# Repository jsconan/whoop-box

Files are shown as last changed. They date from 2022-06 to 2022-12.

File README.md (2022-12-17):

# whoop-box

A printable box system to store tiny-whoops.

<!-- vscode-markdown-toc -->

-   [At a glance](#Ataglance)
-   [Whoop boxes](#Whoopboxes)
-   [Batteries' box](#Batteriesbox)
-   [Angled boxes](#Angledboxes)
-   [Install and requirements](#Installandrequirements)
    -   [OpenSCAD](#OpenSCAD)
    -   [Source code](#Sourcecode)
        -   [Download the zip file](#Downloadthezipfile)
        -   [Get the code from the repository](#Getthecodefromtherepository)
    -   [Configuration](#Configuration)
-   [Render the parts](#Rendertheparts)
-   [Post-scripts](#Post-scripts)

<!-- vscode-markdown-toc-config
	numbering=false
	autoSave=true
	/vscode-markdown-toc-config -->
<!-- /vscode-markdown-toc -->

## At a glance

The project contains designs for a box system for storing tiny-whoop quadcopters. The parts are designed using a scripting language, processed by [OpenSCAD](https://openscad.org/about.html). There is no ready to use 3D model files in the source code. If you are interested in such files, please look at the [released versions](https://github.com/jsconan/whoop-box/releases) which contains 3D model files built with default parameters. However, if you want to customize these parts, tailoring them with your measures, you should rather download the source code and then tweak the configuration files before generating your own 3D model files.

At that time, the project proposes 3 sets of boxes. The dimensions and the number of cells can be set from the [configuration](./config/config-dist.scad).

The size is defined by (in millimeters):

-   The distance between motors, on the [diagonal](./config/config-dist.scad#L61).
-   The diameter of [ducts](./config/config-dist.scad#L62).
-   The height of [ducts](./config/config-dist.scad#L63).
-   The overall height of the [whoop](./config/config-dist.scad#L64).
-   The [padding](./config/config-dist.scad#L65) added between the box wall and the whoop.

A box is also available for enclosing a set of batteries. Its size can be configured too (millimeters):

-   The [width](./config/config-dist.scad#L74) of the battery.
-   The [thickness](./config/config-dist.scad#L75) of the battery.
-   The [length](./config/config-dist.scad#L76) of the battery.

The number of cells for each box is also configurable:

-   The [number of whoops per lines](./config/config-dist.scad#L69) (horizontal).
-   The [number of whoops per columns](./config/config-dist.scad#L70) (vertical).
-   The [number of whoops per lines and columns](./config/config-dist.scad#L71) (depth).
-   The [number of batteries per boxes](./config/config-dist.scad#L79).

Several presets are available out of the box in the file [config/presets.scad](./config/presets-dist.scad). The currently selected preset is configured through the variable `preset` in the file [config/config.scad](./config/config-dist.scad#L58).

When using the [render](./render.sh) script, all presets can be rendered at once using the option `-a`. See the section **[Render the parts](#Rendertheparts)**. Otherwise, only one single preset is rendered at a time.

## Whoop boxes

A second iteration on the project added simple boxes with padding inside to better wrap the tiny-whoop. Instead of multiple shells made of several materials, it only relies on a single box and its container.

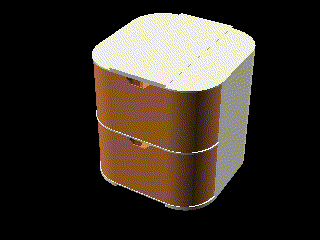
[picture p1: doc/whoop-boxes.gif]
simple box set


This version proposes several variants of the box:

-   A padded box to contain a tiny-whoop

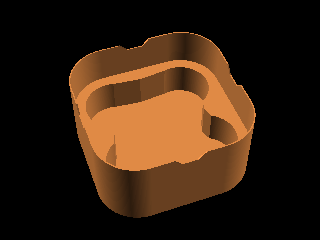
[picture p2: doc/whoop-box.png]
padded box


-   A box for spare parts

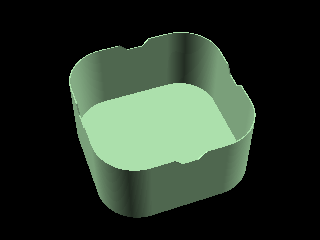
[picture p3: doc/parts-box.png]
spare part box


-   A box for propellers

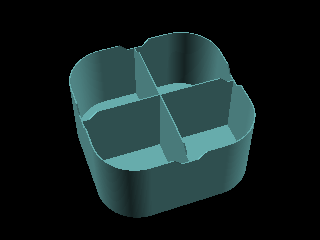
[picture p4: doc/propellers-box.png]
propellers box


-   A container for one or more boxes with respect to the configuration

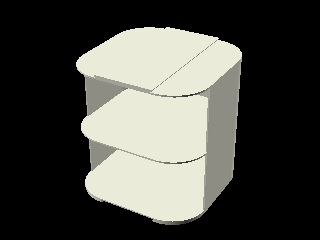
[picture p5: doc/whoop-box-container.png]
container


## Batteries' box

Aside the boxes for containing tiny-whoops, the project also proposes a parametric box for containing the batteries. The size of the batteries and the number per boxes can be configured.

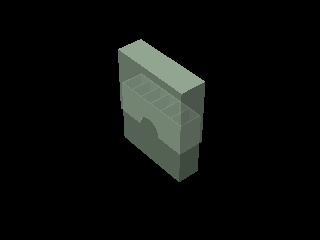
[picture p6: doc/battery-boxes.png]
batteries box


This box is made of two parts:

-   A batteries' container, with separators:

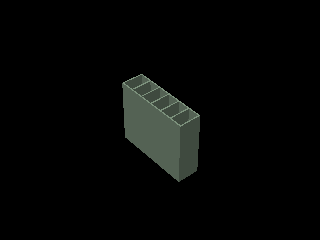
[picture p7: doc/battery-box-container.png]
batteries container


-   A box cover:

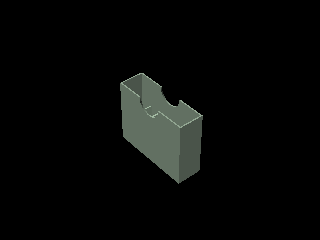
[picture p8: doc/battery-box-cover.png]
box cover


## Angled boxes

Initially, the project was based on a set of wrapped boxes, to be printed in various materials (TPU, PLA, PET). The set was made modular, in order to either have a simple box to protect a tiny-whoop or to properly store several of them in a cupboard.

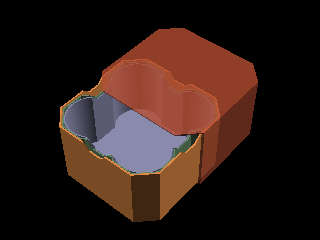
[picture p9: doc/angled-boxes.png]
angled box set


The proposed boxes are:

-   A rounded box to contain a tiny-whoop

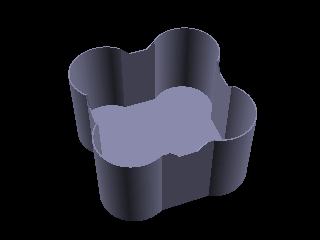
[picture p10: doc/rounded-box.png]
rounded box


-   An angled box to contain the rounded box

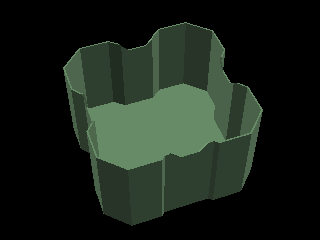
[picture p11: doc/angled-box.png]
angled box


-   A drawer to contain one or more angled boxes with respect to the configuration

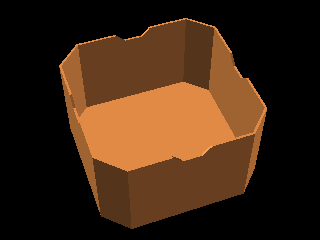
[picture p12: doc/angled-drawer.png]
angled drawer


-   A cupboard to contain drawers with one or more angled boxes with respect to the configuration

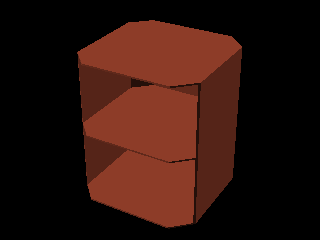
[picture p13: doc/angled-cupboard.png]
angled cupboard


## Install and requirements

To properly use the project you first need to do some installations steps.

### OpenSCAD

First of all you need [OpenSCAD](https://openscad.org/) to be installed. To do so, please go to the [OpenSCAD download page](https://openscad.org/downloads.html), an get the version suitable for your operating system.

### Source code

The source code is hosted on a [Git](https://git-scm.com/) repository. To get it you can either download a [zip file](https://github.com/jsconan/whoop-box/archive/refs/heads/main.zip), or clone the repository locally.

#### Download the zip file

The source code can be downloaded from the [GitHub repository](https://github.com/jsconan/whoop-box).

You can download it as zip file from this [link](https://github.com/jsconan/whoop-box/archive/refs/heads/main.zip).

As the project is using a shared library, that is not supplied with the package, you will need to also download it.

Download the zip file from this [link](https://github.com/jsconan/camelSCAD/archive/refs/heads/main.zip).

Then extract its content inside the folder `lib/camelSCAD`. Please make sure the folder directly contains the library and not an intermediate folder like `lib/camelSCAD/camelSCAD-main`. If this is the case, please move the content one folder up and delete the extra folder.

Note: the easiest way is to call the `init.sh` script, that will take care of this for you.

#### Get the code from the repository

A git tool is needed if you intend to get the source code from the git repository. You can download one either from the [main git website](https://git-scm.com/downloads), or from [GitHub](https://docs.github.com/en/github-cli).

Once you have your git tool installed, open a console window, select a project folder (create it if needed), then run the following commands:

```
git clone https://github.com/jsconan/whoop-box.git
cd whoop-box
git submodule init
git submodule update
```

The source code should have been downloaded, as well as the libraries.

Note: you can also use a graphical interface tool. In this case, please make it can also install the submodules.

Note 2: the easiest way is to call the `init.sh` script, that will take care of this for you.

### Configuration

The configuration may be changed locally. To not collide with changes in the main implementation, the configuration files are not versioned. Instead, you will find `-dist` files that contain a copy of the typical configuration.

From a fresh copy of the project, you will need first to create these configuration files. The easiest way is to call the `init.sh` script, that will take care of this for you. The configuration files will also be checked and created if needed each time the `render.sh` script is called.

This initial creation of the configuration files could also be done manually. Here is how:

1. Go to the `config` folder
2. Copy any of the files having a `-dist` suffix in their name to a file without this suffix.

    _Example:_ copy `config-dist.scad` to `config.scad`

## Render the parts

The parts are all located into the `parts` folder. They can all be opened separately in [OpenSCAD](https://openscad.org/) and rendered.

However, it is possible to render all parts in batch. The script `render.sh` takes care of this.

This is a command-line tool, which accept several parameters. By default, it will render the preset selected in the config.

It is possible to select another preset, as well as set a different number of cells for the containers.

The parameter `-h` make it show the help.

Running the command `render.sh -h` will show this message:

```
Renders OpenSCAD files
  Usage:
	./render.sh [command] [-h|--help] [-o|--option value] files

  a,   all            Render all elements (default)
  n,   angled         Render the sets of angled boxes
  w,   whoop          Render the sets of whoop boxes
  b,   battery        Render the sets of battery boxes
  -h,  --help         Show this help
  -p   --preset       Set the preset to apply
  -a,  --all          Render all presets
  -x,  --line         Set the number of boxes per lines in the container (X-axis)
  -y   --column       Set the number of boxes per columns in the container (Y-axis)
  -z   --depth        Set The number of boxes per lines and columns in the container (Z-axis)
  -b   --batteries    Set The number of batteries per boxes
  -f   --format       Set the output format
  -p   --parallel     Set the number of parallel processes
  -s   --slice        Slice the rendered files using the default configuration
  -c   --clean        Clean up the output folder before rendering
```

All presets can be rendered at once by calling the command `render.sh -a`.

The STL files are rendered to the `dist/stl` folder.

If the slicer [PrusaSlicer](https://github.com/prusa3d/PrusaSlicer) is installed, running the command `render.sh -s` will produce the [G-code](https://en.wikipedia.org/wiki/G-code) from the rendered STL files and using the setting from the file `config/config.ini`. Out of the box, it is produce instruction for PETG and a 0.2mm layer height.

## Post-scripts

When using the built-in script to render/slice the models in batch, you can also add custom post-processing scripts. There is one for `render.sh` and one for `slice.sh`. They are respectively named `post-render.sh` and `post-slice.sh`.

As these script can be defined locally, they are not part of the versioned content. Instead, you can find sample files at `post-render-dist.sh` and `post-slice-dist.sh`. To use them, you need to:

-   copy the dist file to a local file, for example: `cp post-render-dist.sh post-render.sh`.
-   you need to make sure the file is executable: `chmod +x post-render.sh`.
-   finally, add you own commands to the copy.

As an example:

-   The script used to zip the rendered files:

```sh
# Bootstrap the script
scriptpath=$(dirname $0)
source "${scriptpath}/lib/camelSCAD/scripts/utils.sh"

# Script config
project=$(pwd)
stlpath="${project}/dist/stl/"
zippath="stl.zip"
logpath="${project}/dist/zip.log"

# Post process the rendered files
printmessage "${C_MSG}==========================================="
printmessage "${C_MSG}Post-render script: zip files"
dummy=$(
    cd "${stlpath}"
    rm *.zip > /dev/null
    zip -r "${zippath}" *
)
printmessage "${C_MSG}==========================================="
```

-   The script used to copy the sliced files to a SD-card:

```sh
# Bootstrap the script
scriptpath=$(dirname $0)
source "${scriptpath}/lib/camelSCAD/scripts/utils.sh"

# Script config
project=$(pwd)
gcodepath="${project}/dist/gcode/"
sdcardpath="/PATH/TO/SD/CARD"
logpath="${project}/dist/gcode-sync.log"

# Post process the sliced files
printmessage "${C_MSG}==========================================="
printmessage "${C_MSG}Post-slice script: copy Gcode to the SDcard"
date > ${logpath}
createpath "${sdcardpath}"
rsync -ahvt --no-links --delete --partial --force --modify-window=1 --exclude=.DS_Store --log-file=${logpath} "${gcodepath}" "${sdcardpath}"
printmessage "${C_MSG}==========================================="
```

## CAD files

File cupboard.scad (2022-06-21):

/**
 * @license
 * GPLv3 License
 *
 * Copyright (c) 2019-2022 Jean-Sebastien CONAN
 *
 * This file is part of jsconan/whoop-box.
 *
 * jsconan/whoop-box is free software: you can redistribute it and/or modify
 * it under the terms of the GNU General Public License as published by
 * the Free Software Foundation, either version 3 of the License, or
 * (at your option) any later version.
 *
 * jsconan/whoop-box is distributed in the hope that it will be useful,
 * but WITHOUT ANY WARRANTY; without even the implied warranty of
 * MERCHANTABILITY or FITNESS FOR A PARTICULAR PURPOSE.  See the
 * GNU General Public License for more details.
 *
 * You should have received a copy of the GNU General Public License
 * along with jsconan/whoop-box. If not, see <http://www.gnu.org/licenses/>.
 */

/**
 * A box to store tiny-whoops.
 *
 * Cupboard that will contain several tiny-whoops and their surrounding
 * protection boxes. This should be printed in rigid a material, like PLA
 * or PETG.
 *
 * @author jsconan
 */

// Import the project's setup.
include <config/setup.scad>

// Sets the minimum facet angle and size using the defined render mode.
// Displays a build box visualization to preview the printer area.
applyMode(mode=renderMode) {
    // Uncomment the next line to cut a sample from the object
    //sample(size=[DEFAULT_BUILD_PLATE_SIZE, DEFAULT_BUILD_PLATE_SIZE, 5], offset=[0, 0, 20])
    whoopCupboard(
        whoopType = whoopType,
        whoopCount = whoopCountDrawer,
        drawerWallThickness = getBoxWallThickness(DRAWER),
        drawerHeight = getBoxHeight(CUPBOARD, whoopType),
        drawerCount = drawerCountCupboard,
        drawerDistance = getBoxWallDistance(CUPBOARD),
        ductDistance = getBoxWhoopDistance(DRAWER),
        wallThickness = getBoxWallThickness(CUPBOARD)
    );
}

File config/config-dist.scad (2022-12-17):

/**
 * @license
 * GPLv3 License
 *
 * Copyright (c) 2019-2022 Jean-Sebastien CONAN
 *
 * This file is part of jsconan/whoop-box.
 *
 * jsconan/whoop-box is free software: you can redistribute it and/or modify
 * it under the terms of the GNU General Public License as published by
 * the Free Software Foundation, either version 3 of the License, or
 * (at your option) any later version.
 *
 * jsconan/whoop-box is distributed in the hope that it will be useful,
 * but WITHOUT ANY WARRANTY; without even the implied warranty of
 * MERCHANTABILITY or FITNESS FOR A PARTICULAR PURPOSE.  See the
 * GNU General Public License for more details.
 *
 * You should have received a copy of the GNU General Public License
 * along with jsconan/whoop-box. If not, see <http://www.gnu.org/licenses/>.
 */

/**
 * A box to store tiny-whoops.
 *
 * Global configuration.
 *
 * @author jsconan
 */

// We will render the object using the specifications of this mode.
renderMode = MODE_PROD;

// Defines the characteristics of the printer
layerHeight = 0.2;          // The height of the printed layers.
nozzleWidth = 0.4;          // The size of the printer's nozzle.
printTolerance = 0.1;       // The print tolerance when pieces need to be assembled.
printInterval = 5;          // The interval between 2 pieces when presented together.
printerLength = 250;        // The length of the printer's build plate.
printerWidth = 210;         // The width of the printer's build plate.

// Options for the metadata. The render script uses them to extract infos.
showConfig = 0;             // Show the config when rendering a whoop box.
showBatteryConfig = 0;      // Show the config when rendering a battery box.
showPresets = 0;            // Show the list of available presets.
showBatteryPresets = 0;     // Show the list of available battery presets.
showSteps = 0;              // Show the expected number of steps for the whole animation

// Specifications for the boxes
wallThickness = 0.8;        // The thickness of the box walls.
containerThickness = 1.2;   // The thickness of the container walls.
groundThickness = 0.8;      // The thickness of the box ground.
linkThickness = 2;          // The thickness of the link elements.
boxIndentation = [30, 10];  // Defines the size of a handle indentation, it will be cut from each box side. The first value represents the top width, the second represents the bottom width and the depth.
outerDistance = 0.5;        // The distance between a box and its container. This is additional size added to the container inner room to fit the box.

// Select the config preset
preset = "DEFAULT";

// Defines the size of a tiny-whoop
motorDistance = getPreset(preset, IDX_MOTOR_DISTANCE);   // The distance between motors on the diagonal.
ductDiameter = getPreset(preset, IDX_DUCT_DIAMETER);     // The outer diameter of a motor duct.
ductHeight = getPreset(preset, IDX_DUCT_HEIGHT);         // The outer height of a motor duct, including the screw heads.
whoopHeight = getPreset(preset, IDX_WHOOP_HEIGHT);       // The outer height of the tiny-whoop, from the bottom of the frame to the top of the canopy, including everything beyond.
boxPadding = getPreset(preset, IDX_BOX_PADDING);         // The width of padding between the box sides and the tiny-whoop.
boxSeparators = getPreset(preset, IDX_BOX_SEPARATOR);    // Tells whether the box contains separators or not.

// Sets the count of tiny-whoops in each kind of box
whoopBoxX = getPreset(preset, IDX_BOX_X, 1);              // The number of boxes per lines in the container (horizontal axis).
whoopBoxY = getPreset(preset, IDX_BOX_Y, 1);              // The number of boxes per columns in the container (vertical axis).
whoopBoxZ = getPreset(preset, IDX_BOX_Z, 1);              // The number of boxes per lines and columns in the container (depth axis).

// Defines the size of a tiny-whoop's battery
batteryWidth = getBatteryPreset(preset, IDX_BATTERY_WIDTH);    // The battery width.
batteryHeight = getBatteryPreset(preset, IDX_BATTERY_HEIGHT);  // The battery height (thickness).
batteryLength = getBatteryPreset(preset, IDX_BATTERY_LENGTH);  // The battery height.

// Sets the count of batteries in each box
batteryNumber = getBatteryPreset(preset, IDX_BATTERY_NUMBER);  // The number of batteries.

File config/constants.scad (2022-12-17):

/**
 * @license
 * GPLv3 License
 *
 * Copyright (c) 2022 Jean-Sebastien CONAN
 *
 * This file is part of jsconan/whoop-box.
 *
 * jsconan/whoop-box is free software: you can redistribute it and/or modify
 * it under the terms of the GNU General Public License as published by
 * the Free Software Foundation, either version 3 of the License, or
 * (at your option) any later version.
 *
 * jsconan/whoop-box is distributed in the hope that it will be useful,
 * but WITHOUT ANY WARRANTY; without even the implied warranty of
 * MERCHANTABILITY or FITNESS FOR A PARTICULAR PURPOSE.  See the
 * GNU General Public License for more details.
 *
 * You should have received a copy of the GNU General Public License
 * along with jsconan/whoop-box. If not, see <http://www.gnu.org/licenses/>.
 */

/**
 * A box to store tiny-whoops.
 *
 * Global constants.
 *
 * @author jsconan
 */

// Defines the indexes in the presets
IDX_NAME           =  0; // The index for the preset name.
IDX_MOTOR_DISTANCE =  1; // The index for the distance between motors on the diagonal.
IDX_DUCT_DIAMETER  =  2; // The index for the outer diameter of a motor duct.
IDX_DUCT_HEIGHT    =  3; // The index for the outer height of a motor duct, including everything beyond like the screw heads.
IDX_WHOOP_HEIGHT   =  4; // The index for the outer height of the tiny-whoop, from the bottom of the frame to the top of the canopy, including everything beyond.
IDX_BOX_PADDING    =  5; // The index for the width of padding between the box sides and the tiny-whoop.
IDX_BOX_SEPARATOR  =  6; // The index for the flag allowing to add separators.
IDX_BOX_X          =  7; // The index for the number of boxes per lines in the container (horizontal axis).
IDX_BOX_Y          =  8; // The index for the number of boxes per columns in the container (vertical axis).
IDX_BOX_Z          =  9; // The index for the number of boxes per lines and columns in the container (depth axis).
IDX_BATTERY_WIDTH  =  1; // The index for the battery width.
IDX_BATTERY_HEIGHT =  2; // The index for the battery height.
IDX_BATTERY_LENGTH =  3; // The index for the battery length.
IDX_BATTERY_NUMBER =  4; // The index for the number of batteries per box.

// Colors applied to the elements when previewed.
// This will be used for the animations and other pictures, but this won't have effect on the ready to print elements.
colorWhoopBox = "#d84";                         // Color of a simple whoop box.
colorPropellersBox = "#6aa";                    // Color of a box for propellers.
colorPartsBox = "#ada";                         // Color of a box for spare parts.
colorWhoopBoxContainer = "#eed";                // Color of a whoop box container.
colorAngledBox = "#686";                        // Color of an angled box.
colorRoundedBox = "#88a";                       // Color of a rounded box.
colorAngledDrawer = "#d84";                     // Color of a drawer for angled boxes.
colorAngledCupboard = [.7, .3, .2, .8];         // Color of a cupboard for angled boxes.
colorBatteryBoxContainer = [.6, .7, .6, .8];    // Color of a battery container.
colorBatteryBoxCover = [.7, .8, .7, .8];        // Color of a battery box cover.

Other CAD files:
pictures/angled-cupboard.scad
angled-box.scad
config/helpers.scad
config/presets-dist.scad
config/setup.scad
config/version.scad
container.scad
drawer.scad
parts/angled/angled-box.scad
parts/angled/angled-container.scad
parts/angled/angled-cupboard.scad
parts/angled/angled-drawer.scad
parts/angled/rounded-box.scad
parts/battery/battery-box-container.scad
parts/battery/battery-box-cover.scad
parts/battery/battery-box.scad
parts/whoop/whoop-box-container.scad
parts/whoop/whoop-box.scad
pictures/angled-box.scad
pictures/angled-boxes.scad
pictures/angled-drawer.scad
pictures/battery-box-container.scad
pictures/battery-box-cover.scad
pictures/battery-boxes.scad
pictures/parts-box.scad
pictures/propellers-box.scad
pictures/rounded-box.scad
pictures/whoop-box-container.scad
pictures/whoop-box.scad
pictures/whoop-boxes.scad
rounded-box.scad
shapes/angled-box.scad
shapes/angled-container.scad
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

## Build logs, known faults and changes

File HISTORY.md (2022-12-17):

# whoop-box history

## [Version 1.1.0](https://github.com/jsconan/whoop-box/releases/tag/1.1.0)

Features:

-   Add a box containing a set of batteries.
    batteries box

-   Add actual example for the post render scripts.
-   Add a preset for Meteor65 Pro 2022 edition

Fixes:

-   Add a forgotten picture in the readme.
-   Fix a misaligned comment.
-   Fix an error appearing when running the post-render script sample.
-   Fix a few glitches in the readme file.

## [Version 1.0.0](https://github.com/jsconan/whoop-box/releases/tag/1.0.0)

Add another set of boxes with padding inside to better wrap the tiny-whoop. Instead of multiple shells made of several materials, it only relies on a single box and its container.

whoop box

Also add better config possibilities, as well as a few scripts and a more detailed readme.

## [Version 0.1.1](https://github.com/jsconan/whoop-box/releases/tag/0.1.1)

Finalize the import from the `things` project:

-   fix the license headers
-   move setup and helpers to a proper place
-   manage the project version as a constant
-   add an history file

## [Version 0.1.0](https://github.com/jsconan/whoop-box/releases/tag/0.1.0)

Whoop box project: A box to store tiny-whoops.

---

Notes:

-   Import from the repository [jsconan/things](https://github.com/jsconan/things)
-   Extract of the pull request https://github.com/jsconan/things/pull/27

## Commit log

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2022-06-19 refactor: move file to the root, and fix the internal paths
    [all-box.scad, angled-box.scad, box-util.scad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]
2022-06-21 doc: fix project name in license headers
    [all-box.scad, angled-box.scad, box-util.scad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]
2022-06-21 refactor: move setup and helpers to the config folder
    [all-box.scad, angled-box.scad, container.scad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]
2022-06-21 feature: add the version as a constant
    [all-box.scad, angled-box.scad, box-util.scad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]
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2022-06-23 refactor: split the config, moving constants to a specific file
    [config-old.scad, config.scad, constants.scad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]
2022-06-23 feature: rework the helpers, adding functions to compute the shape placements
    [helpers.scad]
2022-06-23 refactor: move the parts to a proper folder
    [angled-box.scad, container.scad, cupboard.scad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]
2022-06-26 refactor: simplify the config by only managing one tiny-whoop size, also prepare config for other sizes
    [all-box.scad, angled-box.scad, config-old.scad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]
2022-06-26 refactor: use extrudePolygon instead of local implementation
    [angled-box.scad, container.scad, cupboard.scad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]
2022-06-26 refactor: remove the data helpers and use direct data instead
    [all-box.scad, angled-box.scad, box-util.scad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]
2022-06-26 feat: add the simple box shape
    [angled-box.scad, setup.scad, whoop-box.scad]
2022-06-26 refactor: rename the shapes and parts for better clarity
    [all-box.scad, angled-box.scad, angled-container.scad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]
2022-06-26 fix: center the cupboard shape, add it to the test preview
    [all-box.scad, angled-cupboard.scad]
2022-06-26 feat: add a container for the whoop boxes
    [whoop-box-container.scad, whoop-box.scad]
2022-06-26 feat: add a test for the whoop-boxes
    [angled-boxes.scad, whoop-boxes.scad]
2022-06-26 feat: use presets for the config in order to support various sizes
    [angled-container.scad, angled-cupboard.scad, angled-drawer.scad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]
2022-06-26 feat: remove the local config from the CVS and add dist files
    [config-dist.scad]
2022-06-27 refactor: move the getPreset() helper out from the presets file
    [helpers.scad, presets.scad, setup.scad]
2022-06-27 feat: remove the local presets from the CVS and add a dist file
    [presets-dist.scad]
2022-06-28 fix: wrong preset name for the frame 75 HD
    [presets-dist.scad]
2022-06-28 feat: reduce padding for the frame 75
    [presets-dist.scad]
2022-06-28 feat: add a helper to get the list of preset values
    [helpers.scad]
2022-06-28 feat: add an option to render all presets
    [config-dist.scad, setup.scad]
2022-06-29 feat: add a way to link together several box containers
    [config-dist.scad, whoop-box-container.scad, whoop-box.scad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]
2022-06-30 fix: adjust the box height for the frame 75
    [presets-dist.scad]
2022-06-30 feat: add a config for the thickness of the container walls
    [angled-boxes.scad, angled-container.scad, angled-cupboard.scad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]
2022-06-30 fix: adjust the design of the whoop box container for a better accuracy, also fix the positionning of the elements
    [whoop-box.scad]
2022-07-01 refactor: make the box padding part of the indented shape
    [whoop-box.scad]
2022-07-02 refactor: move the parts to subfolders for a better split
    [angled-box.scad, angled-container.scad, angled-cupboard.scad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]
2022-07-03 fix: outline error with the rounded-box
    [rounded-box.scad]
2022-07-03 refactor: give a better name to the config properties for the number of boxes
    [angled-container.scad, angled-cupboard.scad, angled-drawer.scad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]
2022-07-04 feat: make optional the box padding
    [whoop-box.scad]
2022-07-04 feat: add presets for parts boxes
    [presets-dist.scad]
2022-07-07 feat: add an option to place separators in whoop boxes
    [box-util.scad, config-dist.scad, constants.scad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]
2022-07-08 feat: make the number of boxes on each axis part of the presets
    [config-dist.scad, constants.scad, helpers.scad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]
2022-07-08 feat: add presets for props boxes, and split the parts75 into low and high profiles
    [presets-dist.scad]
2022-07-09 test: add the separator option to the visual test of the whoop-box
    [whoop-boxes.scad]
2022-07-09 doc: typo in parameters description
    [helpers.scad]
2022-07-09 fix: take care of the size of the roof for the box height with shells
    [angled-boxes.scad, angled-cupboard.scad, helpers.scad]
2022-08-05 doc: remove useless comments
    [angled-box.scad, angled-boxes.scad, angled-container.scad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]
2022-08-05 feat: add pictures to show the models of whoop boxes
    [angled-box.scad, angled-boxes.scad, angled-cupboard.scad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]
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2022-08-06 fix: error when running the post-render sample
2022-08-06 doc: fix the post-render script sample
2022-12-12 feat: add a preset for Meteor65 Pro 2022 edition
    [presets-dist.scad]
2022-12-12 fix: increase the duct height for Meteor65 Pro 2022 edition
    [presets-dist.scad]
2022-12-13 feat: add presets for defining battery boxes
    [config-dist.scad, constants.scad, helpers.scad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]
2022-12-13 feat: add a battery box
    [battery-box.scad, setup.scad]
2022-12-13 feat: add a battery box cover
    [battery-box.scad, battery-cover.scad]
2022-12-13 feat: add test for the battery boxes
    [battery-boxes.scad]
2022-12-13 feat: add script for rendering the battery boxes
    [config-dist.scad, setup.scad]
2022-12-13 fix: adjust the size of the battery box
    [battery-box.scad, battery-boxes.scad]
2022-12-13 refactor: simplify the render script
    [battery-box.scad, battery-cover.scad]
2022-12-14 feat: add a model for printing together the battery container and the cover
    [battery-box-container.scad, battery-box-cover.scad]
2022-12-14 feat: size the battery box as a percentage of the battery length
    [battery-box.scad, battery-boxes.scad]
2022-12-14 feat: separate the printed infos between whoop boxes and battery boxes
    [config-dist.scad, helpers.scad, setup.scad]
2022-12-14 feat: add separators in the battery box cover
    [battery-box.scad]
2022-12-15 doc: set the correct description for the battery box parts
    [battery-box-container.scad, battery-box-cover.scad, battery-box.scad]
2022-12-15 feat: add pictures for the battery box parts
    [battery-box-container.scad, battery-box-cover.scad, battery-boxes.scad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]
2022-12-17 feat: adjust the size of the cover part with separators
    [battery-box.scad]
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2022-12-17 feat: simplify the config, unifying the preset selection
    [config-dist.scad, helpers.scad, setup.scad]
2022-12-17 doc: update the readme, fixing links
    [config-dist.scad]
